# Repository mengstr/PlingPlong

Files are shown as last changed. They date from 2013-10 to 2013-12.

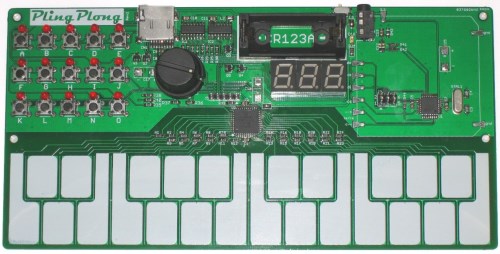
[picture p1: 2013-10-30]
Doc/PCB-r1-small.jpg

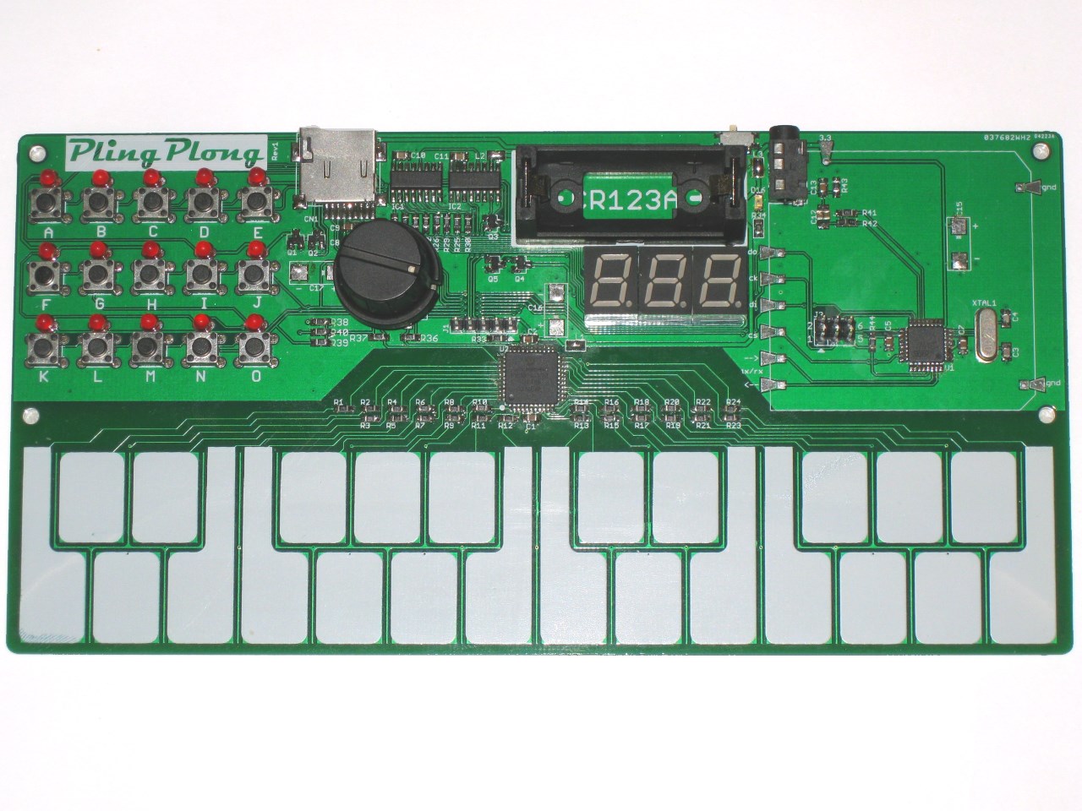
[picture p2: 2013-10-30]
Doc/PCB-r1.jpg

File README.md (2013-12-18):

## PingPlong

This is a small (10x20cm 4x8") portable battery-operated synth with a two octave touch keyboard and four voice polyphonic digital sound. A video of the board in action is available at http://youtu.be/FlVGMttL9SU

Photo of the soldered board

Two microcontrollers are used on the board - a Microchip PIC18F44K22 for the user interface and a Atmel ATMEGA328 for the sound generation.

The PIC18 is using the internal CMTU module for capacitively sensing the 24 touch keys. It is also in charge of scanning the 15 tactile buttons, refreshing the 15 status LEDs and the 7-segment displays, and polling the Rotary Encoder.

Whenever a padis touched or the rotary encoder is turned a standard Note On/Off or Control Change MIDI message is sent to the ATMEGA328 for playing.

Currently the MEGA328 is running a straight copy of the [Midi Vampire-I](http://wiki.openmusiclabs.com/wiki/MidiVamp1) firmware. The MEGA328 is also connected to a SD-card connector for future use - I want to do firmware updates via the SD card.

The sound-generating part is contained in a 5x5cm "selfcontained" area to the right on the pcb having pads and via holes for power, midi and SD-card signals. This makes it easy to replace just the synth with something else than the MidiVamp. Just design a new 5x5 cm pcb and solder it to the pads on the main board and it's done.



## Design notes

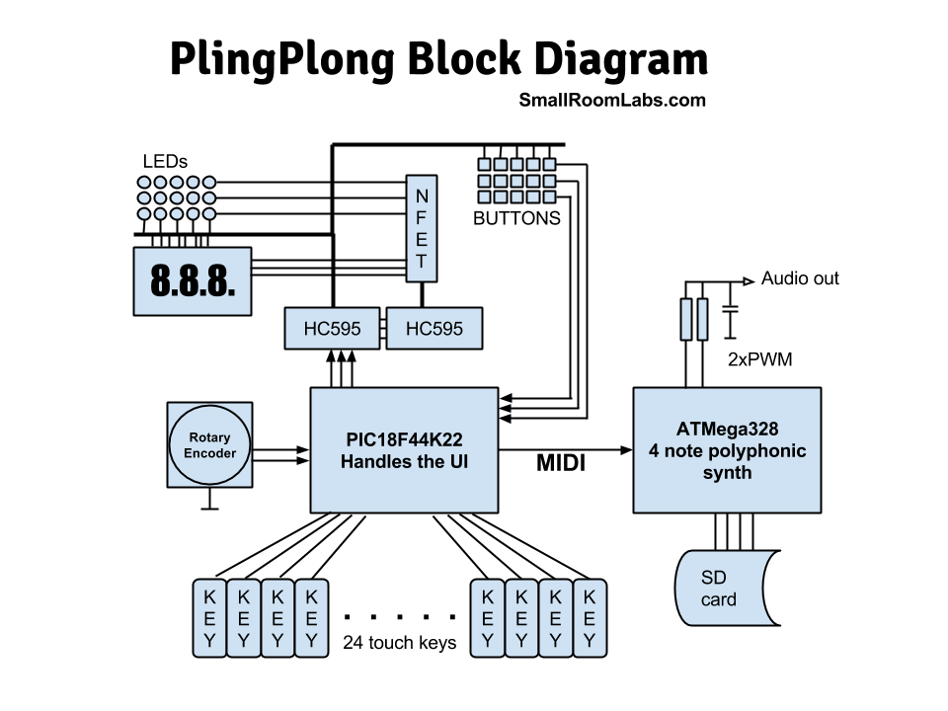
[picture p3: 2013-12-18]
Doc/PlingPlong Block diagram.png

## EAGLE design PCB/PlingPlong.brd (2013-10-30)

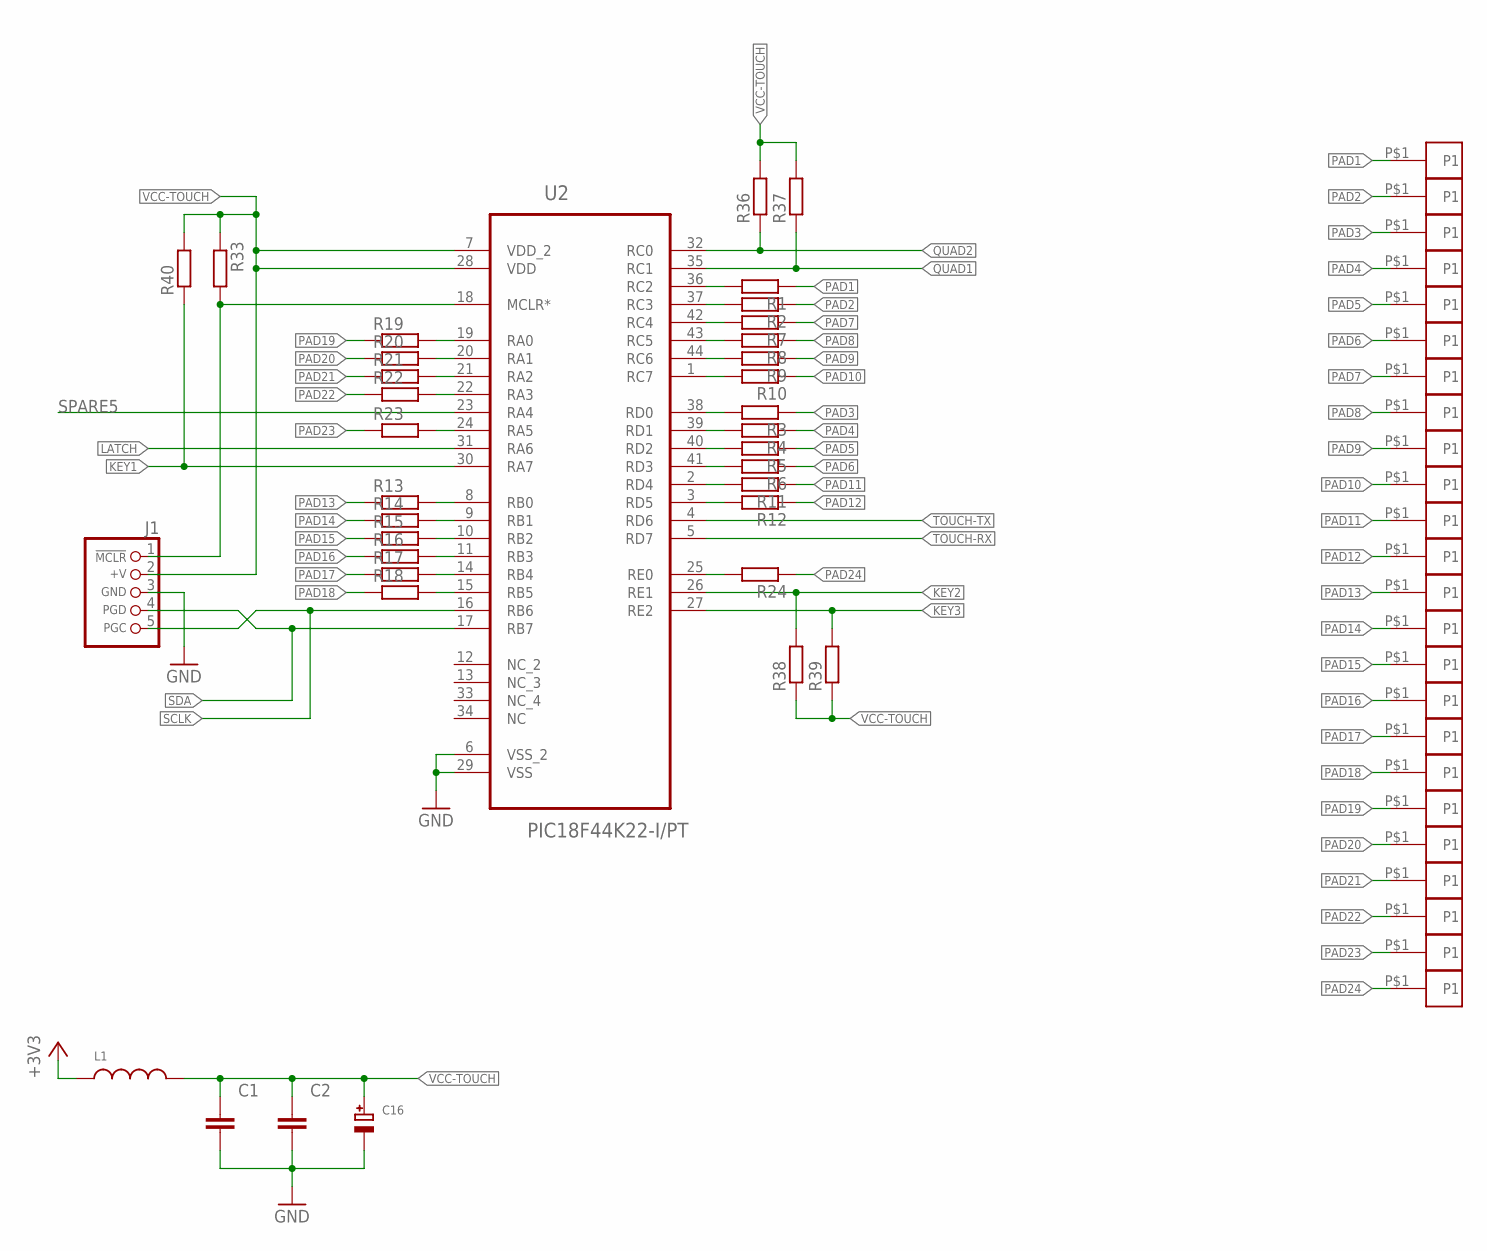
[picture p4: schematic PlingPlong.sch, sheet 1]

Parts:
C1, C2: CAPACITOR_NPOL-0805; C805
C16: CAP_TANTALUMD/7343_WAVE; EIA7343-31/D-W
J1: CON_HEADER_PRG_PIC_ICSPB; HEADER_PRG_1X05_ICSP_B
L1: INDUCTOR0805; 0805
P1, P2, P3, P4, P5, P6, P7, P8, P9, P10, P11, P12, P13, P14, P15, P16, P17, P18, P19, P20, P21, P22, P23, P24: PAD-NOSTOP; PAD1X1NOSTOP
R1, R2, R3, R4, R5, R6, R7, R8, R9, R10, R11, R12, R13, R14, R15, R16, R17, R18, R19, R20, R21, R22, R23, R24, R33, R36, R37, R38, R39, R40: R-EU_R0805W; R0805W
U2: PIC18F44K22-I/PT; QFP80P1200X1200X120-44N

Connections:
+3V3: L1.1; also elsewhere on the board
GND: C1.2, C2.2, C16.-, J1.3 (GND), U2.6 (VSS_2), U2.29 (VSS); also elsewhere on the board
KEY1: R40.1, U2.30 (RA7); also elsewhere on the board
KEY2: R38.2, U2.26 (RE1); also elsewhere on the board
KEY3: R39.2, U2.27 (RE2); also elsewhere on the board
LATCH: U2.31 (RA6); also elsewhere on the board
unnamed: R13.2, U2.8 (RB0)
unnamed: R14.2, U2.9 (RB1)
unnamed: R15.2, U2.10 (RB2)
unnamed: R16.2, U2.11 (RB3)
unnamed: R17.2, U2.14 (RB4)
unnamed: R18.2, U2.15 (RB5)
unnamed: R23.2, U2.24 (RA5)
unnamed: R19.2, U2.19 (RA0)
unnamed: R20.2, U2.20 (RA1)
unnamed: R21.2, U2.21 (RA2)
unnamed: R22.2, U2.22 (RA3)
unnamed: R1.2, U2.36 (RC2)
unnamed: R2.2, U2.37 (RC3)
unnamed: R7.2, U2.42 (RC4)
unnamed: R8.2, U2.43 (RC5)
unnamed: R9.2, U2.44 (RC6)
unnamed: R10.2, U2.1 (RC7)
unnamed: R24.2, U2.25 (RE0)
unnamed: J1.1 (/MCLR), R33.2, U2.18 (MCLR*)
unnamed: R12.2, U2.3 (RD5)
unnamed: R11.2, U2.2 (RD4)
unnamed: R6.2, U2.41 (RD3)
unnamed: R5.2, U2.40 (RD2)
unnamed: R4.2, U2.39 (RD1)
unnamed: R3.2, U2.38 (RD0)
PAD1: P1.P$1, R1.1
PAD2: P2.P$1, R2.1
PAD3: P3.P$1, R3.1
PAD4: P4.P$1, R4.1
PAD5: P5.P$1, R5.1
PAD6: P6.P$1, R6.1
PAD7: P7.P$1, R7.1
PAD8: P8.P$1, R8.1
PAD9: P9.P$1, R9.1
PAD10: P10.P$1, R10.1
PAD11: P11.P$1, R11.1
PAD12: P12.P$1, R12.1
PAD13: P13.P$1, R13.1
PAD14: P14.P$1, R14.1
PAD15: P15.P$1, R15.1
PAD16: P16.P$1, R16.1
PAD17: P17.P$1, R17.1
PAD18: P18.P$1, R18.1
PAD19: P19.P$1, R19.1
PAD20: P20.P$1, R20.1
PAD21: P21.P$1, R21.1
PAD22: P22.P$1, R22.1
PAD23: P23.P$1, R23.1
PAD24: P24.P$1, R24.1
QUAD1: R37.1, U2.35 (RC1); also elsewhere on the board
QUAD2: R36.1, U2.32 (RC0); also elsewhere on the board
SCLK: J1.5 (PGC), U2.16 (RB6); also elsewhere on the board
SDA: J1.4 (PGD), U2.17 (RB7); also elsewhere on the board
SPARE5: U2.23 (RA4)
TOUCH-RX: U2.5 (RD7); also elsewhere on the board
TOUCH-TX: U2.4 (RD6); also elsewhere on the board
VCC-TOUCH: C1.1, C2.1, C16.+, J1.2 (+V), L1.2, R33.1, R36.2, R37.2, R38.1, R39.1, R40.2, U2.7 (VDD_2), U2.28 (VDD)

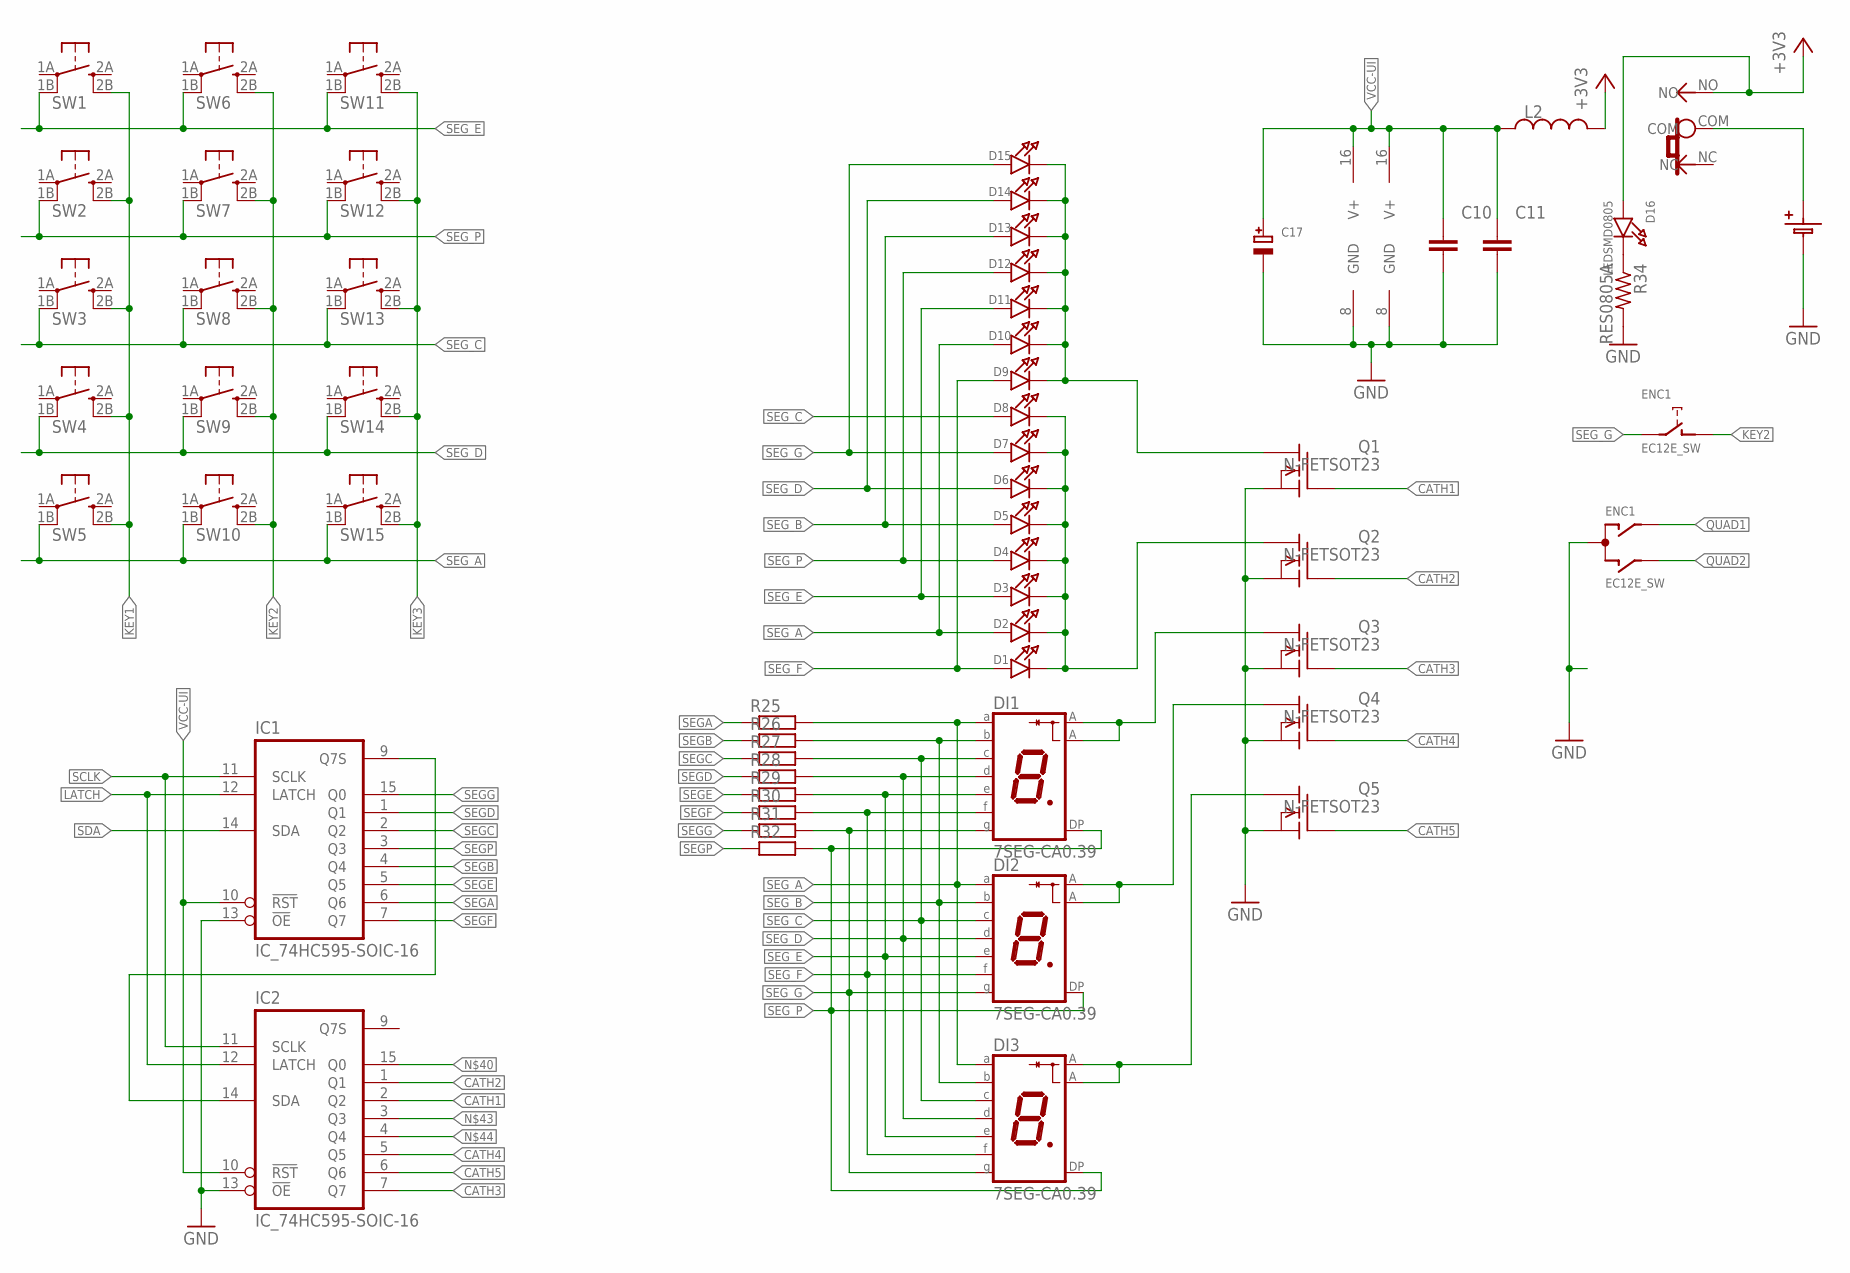
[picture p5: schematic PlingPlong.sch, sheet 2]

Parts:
BA1: BATTERY1-123PIN; BATTERY-CR123A-PINS
C10, C11: CAPACITOR_NPOL-0805; C805
C17: CAP_TANTALUMD/7343_WAVE; EIA7343-31/D-W
D1, D2, D3, D4, D5, D6, D7, D8, D9, D10, D11, D12, D13, D14, D15: LED3MM
D16: LEDSMD0805; CHIPLED_0805
DI1, DI2, DI3: 7SEG-CA0.39; LG3911
ENC1: EC12E_SW; ALPS_EC12E_SW
IC1, IC2: IC_74HC595-SOIC-16; SOIC-16
L2: INDUCTOR0805; 0805
Q1, Q2, Q3, Q4, Q5: N-FETSOT23; SOT23
R25, R26, R27, R28, R29, R30, R31, R32: R-EU_R0805W; R0805W
R34: RES0805A; R0805A
SW1, SW2, SW3, SW4, SW5, SW6, SW7, SW8, SW9, SW10, SW11, SW12, SW13, SW14, SW15: TACTILETACT-6X6-PTH; TACTILE-PTH
SW16: SLIDESWITCH-PCM12; PCM12

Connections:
+3V3: D16.A, L2.2, SW16.NO; also elsewhere on the board
CATH1: IC2.2 (Q2), Q1.1 (G)
CATH2: IC2.1 (Q1), Q2.1 (G)
CATH3: IC2.7 (Q7), Q3.1 (G)
CATH4: IC2.5 (Q5), Q4.1 (G)
CATH5: IC2.6 (Q6), Q5.1 (G)
CATH_1: D9.C, D10.C, D11.C, D12.C, D13.C, D14.C, D15.C, Q1.3 (D)
CATH_2: D1.C, D2.C, D3.C, D4.C, D5.C, D6.C, D7.C, D8.C, Q2.3 (D)
CATH_3: DI1.P$3 (A), DI1.P$8 (A), Q3.3 (D)
CATH_4: DI2.P$3 (A), DI2.P$8 (A), Q4.3 (D)
CATH_5: DI3.P$3 (A), DI3.P$8 (A), Q5.3 (D)
GND: BA1.NEG, C10.2, C11.2, C17.-, ENC1.C, IC1.8 (GND), IC1.13 (!OE), IC2.8 (GND), IC2.13 (!OE), Q1.2 (S), Q2.2 (S), Q3.2 (S), Q4.2 (S), Q5.2 (S), R34.2; also elsewhere on the board
KEY1: SW1.2B, SW2.2B, SW3.2B, SW4.2B, SW5.2B; also elsewhere on the board
KEY2: ENC1.D (1), SW6.2B, SW7.2B, SW8.2B, SW9.2B, SW10.2B; also elsewhere on the board
KEY3: SW11.2B, SW12.2B, SW13.2B, SW14.2B, SW15.2B; also elsewhere on the board
LATCH: IC1.12 (LATCH), IC2.12 (LATCH); also elsewhere on the board
unnamed: IC1.9 (Q7S), IC2.14 (SDA)
unnamed: BA1.POS (POS1), SW16.COM
unnamed: D16.C, R34.1
QUAD1: ENC1.A; also elsewhere on the board
QUAD2: ENC1.B; also elsewhere on the board
SCLK: IC1.11 (SCLK), IC2.11 (SCLK); also elsewhere on the board
SDA: IC1.14 (SDA); also elsewhere on the board
SEGA: IC1.6 (Q6), R25.1
SEGB: IC1.4 (Q4), R26.1
SEGC: IC1.2 (Q2), R27.1
SEGD: IC1.1 (Q1), R28.1
SEGE: IC1.5 (Q5), R29.1
SEGF: IC1.7 (Q7), R30.1
SEGG: IC1.15 (Q0), R31.1
SEGP: IC1.3 (Q3), R32.1
SEG_A: D2.A, D10.A, DI1.P$10 (A), DI2.P$10 (A), DI3.P$10 (A), R25.2, SW5.1B, SW10.1B, SW15.1B
SEG_B: D5.A, D13.A, DI1.P$9 (B), DI2.P$9 (B), DI3.P$9 (B), R26.2
SEG_C: D8.A, DI1.P$7 (C), DI2.P$7 (C), DI3.P$7 (C), R27.2, SW3.1B, SW8.1B, SW13.1B
SEG_D: D6.A, D14.A, DI1.P$5 (D), DI2.P$5 (D), DI3.P$5 (D), R28.2, SW4.1B, SW9.1B, SW14.1B
SEG_E: D3.A, D11.A, DI1.P$2 (E), DI2.P$2 (E), DI3.P$2 (E), R29.2, SW1.1B, SW6.1B, SW11.1B
SEG_F: D1.A, D9.A, DI1.P$1 (F), DI2.P$1 (F), DI3.P$1 (F), R30.2
SEG_G: D7.A, D15.A, DI1.P$6 (G), DI2.P$6 (G), DI3.P$6 (G), ENC1.E (2), R31.2
SEG_P: D4.A, D12.A, DI1.P$4 (DP), DI2.P$4 (DP), DI3.P$4 (DP), R32.2, SW2.1B, SW7.1B, SW12.1B
VCC-UI: C10.1, C11.1, C17.+, IC1.10 (!RST), IC1.16 (V+), IC2.10 (!RST), IC2.16 (V+), L2.1

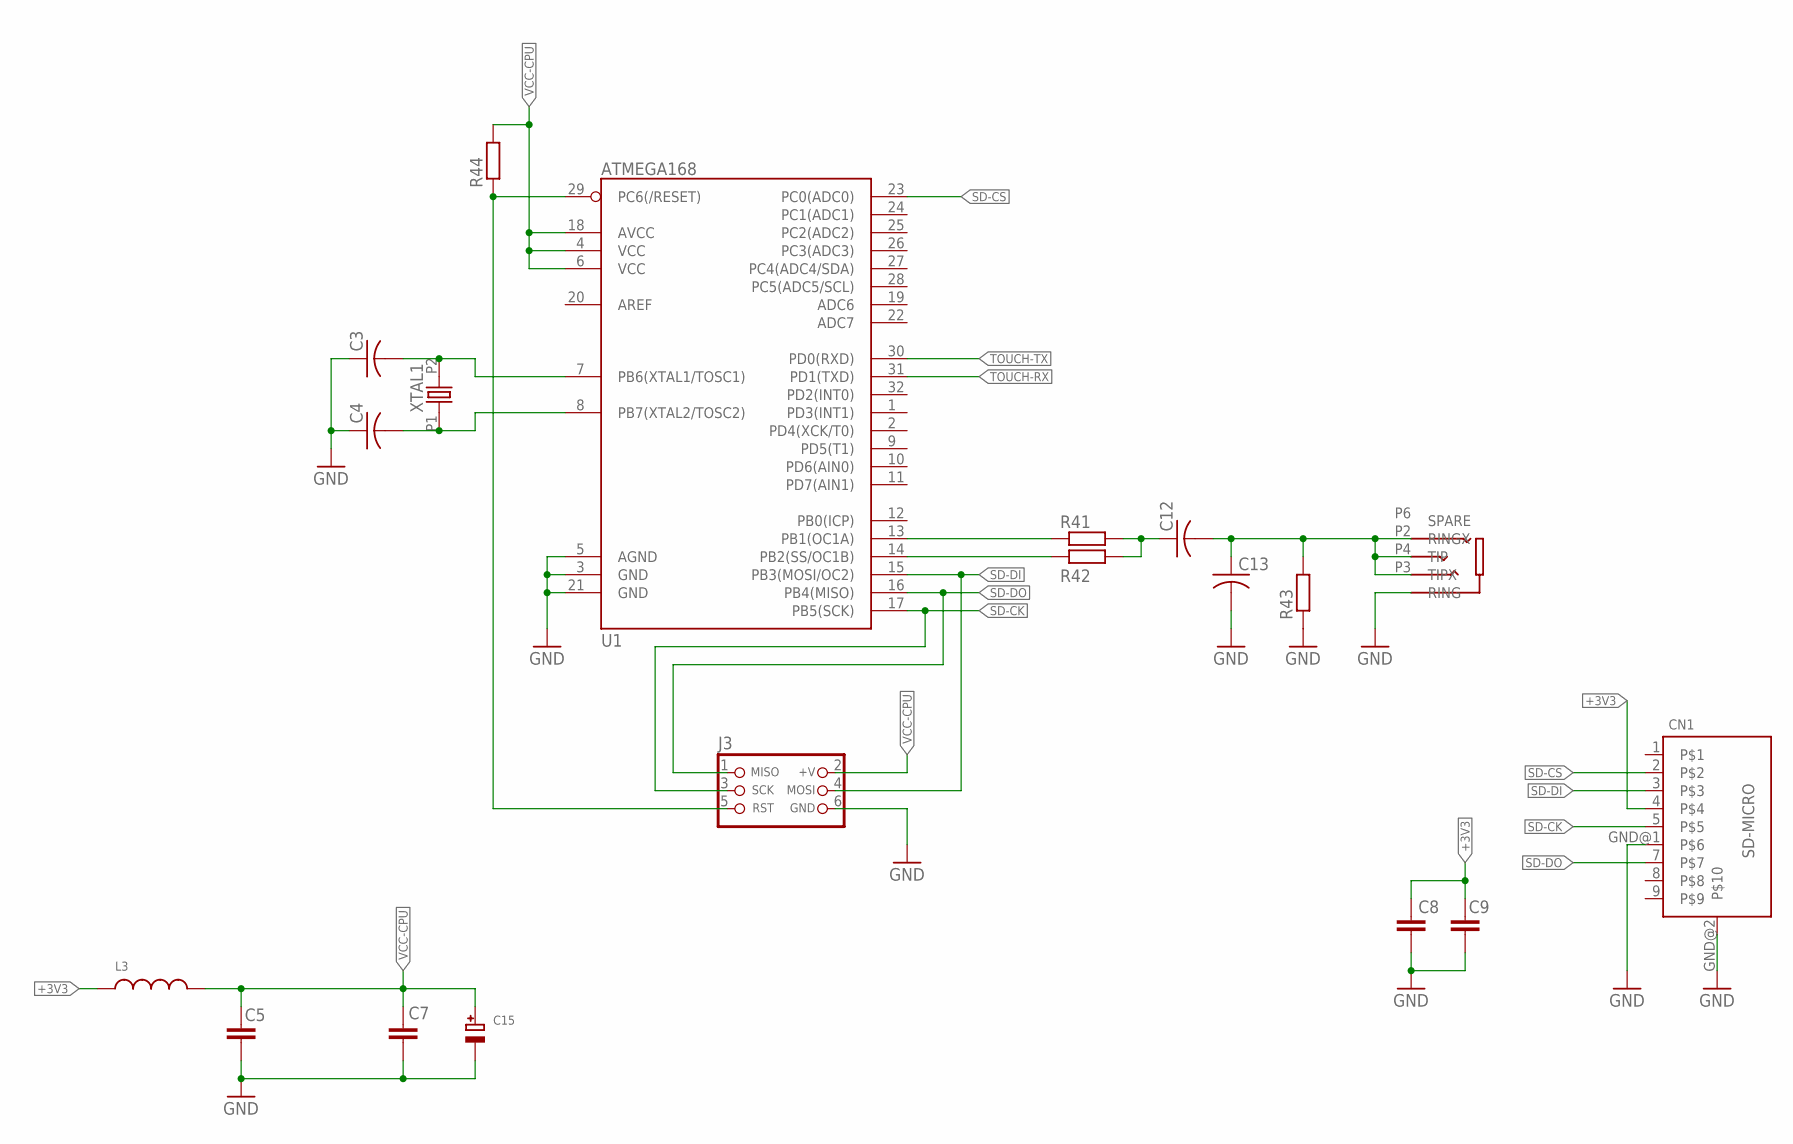
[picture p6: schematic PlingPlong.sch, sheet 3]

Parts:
C3, C4, C13: C-USC0805; C0805
C5, C7, C8, C9: CAPACITOR_NPOL-0805; C805
C12: C-USC1206; C1206
C15: CAP_TANTALUMD/7343_WAVE; EIA7343-31/D-W
CN1: SD-MICRO; MICROSD-TFP09
J3: CON_HEADER_PRG_AVR_ICSP; HEADER_PRG_2X03
L3: INDUCTOR0805; 0805
R41, R42, R43, R44: R-EU_R0805W; R0805W
U1: ATMEGA168; TQFP32-08
U$2: JACK4-PJ320; PJ-320E
XTAL1: OSC-XTAL-HC-49U-PTH; HC-49U-PTH

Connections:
+3V3: C8.1, C9.1, CN1.4, L3.1; also elsewhere on the board
CPU-RESET: J3.5 (RST), R44.1, U1.29 (PC6(/RESET))
GND: C3.1, C4.1, C5.2, C7.2, C8.2, C9.2, C13.2, C15.-, CN1.GND@1, CN1.GND@2, J3.6 (GND), R43.1, U1.3 (GND), U1.5 (AGND), U1.21 (GND), U$2.P5 (RING); also elsewhere on the board
unnamed: R41.1, U1.13 (PB1(OC1A))
unnamed: R42.1, U1.14 (PB2(SS/OC1B))
unnamed: C12.1, R41.2, R42.2
unnamed: C12.2, C13.1, R43.2, U$2.P2 (RINGX), U$2.P3 (TIPX), U$2.P4 (TIP)
unnamed: C3.2, U1.7 (PB6(XTAL1/TOSC1)), XTAL1.P2 (2)
unnamed: C4.2, U1.8 (PB7(XTAL2/TOSC2)), XTAL1.P1 (1)
SD-CK: CN1.5, J3.3 (SCK), U1.17 (PB5(SCK))
SD-CS: CN1.2, U1.23 (PC0(ADC0))
SD-DI: CN1.3, J3.4 (MOSI), U1.15 (PB3(MOSI/OC2))
SD-DO: CN1.7, J3.1 (MISO), U1.16 (PB4(MISO))
TOUCH-RX: U1.31 (PD1(TXD)); also elsewhere on the board
TOUCH-TX: U1.30 (PD0(RXD)); also elsewhere on the board
VCC-CPU: C5.1, C7.1, C15.+, J3.2 (+V), L3.2, R44.2, U1.4 (VCC), U1.6 (VCC), U1.18 (AVCC)

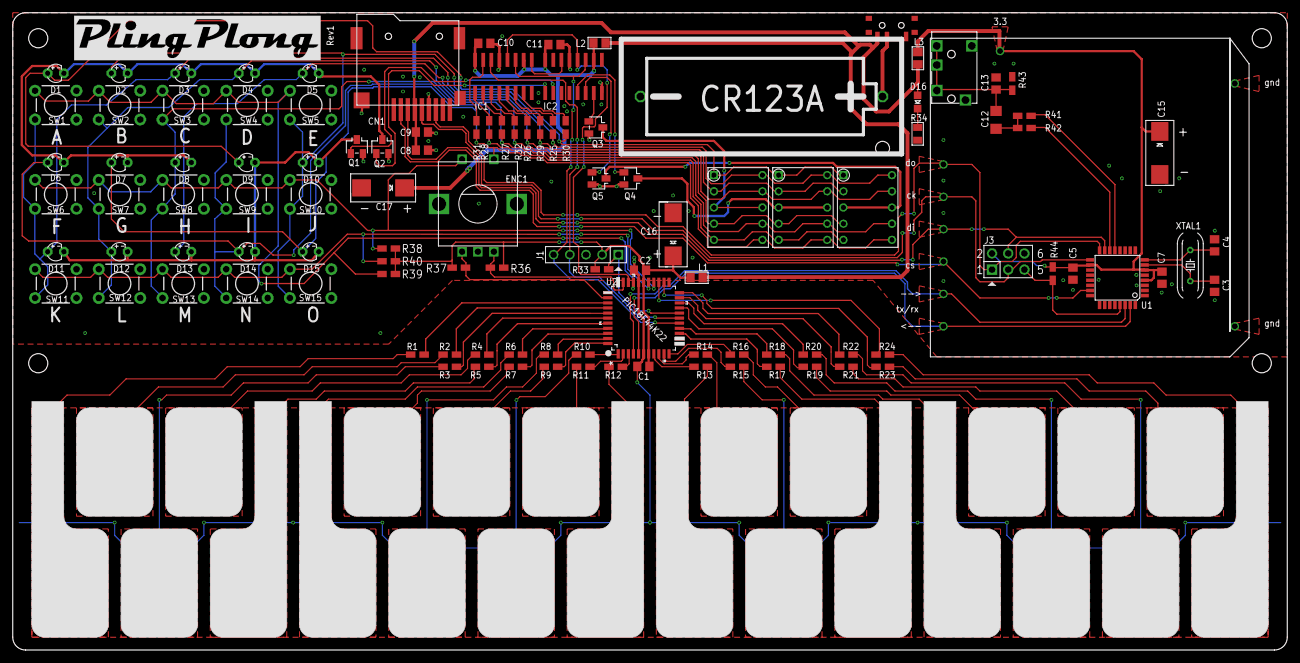
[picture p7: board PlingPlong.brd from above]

Board: 2 copper layers, 200.0 x 100.0 mm, 136 parts (0 on the bottom side), 104 nets.

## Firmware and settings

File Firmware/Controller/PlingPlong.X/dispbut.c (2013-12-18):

#include <stdint.h>         /* For uint8_t definition */
#include <stdbool.h>        /* For true/false definition */
#include <xc.h>
#include "dispbut.h"

#define KEY1            PORTAbits.RA7
#define KEY2            PORTEbits.RE1
#define KEY3            PORTEbits.RE2

#define LATCH595        LATAbits.LA6
#define CLK595          LATBbits.LB6
#define DATA595         LATBbits.LB7


volatile uint8_t    disp[3];
volatile uint16_t   leds;
volatile uint16_t   keys;
volatile uint8_t    butt;

const uint8_t charmap[]={
    0x00,0x82,0x21,0x00,0x00,0x00,0x00,0x02,0x39,0x0f,0x00,0x00,0x00,0x40,0x80,0x52,	//  !"#$%&'()*+,-./
    0x3f,0x06,0x5b,0x4f,0x66,0x6d,0x7d,0x07,0x7f,0x6f,0x09,0x00,0x00,0x48,0x00,0x53,	// 0123456789:;<=>?
    0x00,0x77,0x7c,0x39,0x5e,0x79,0x71,0x6f,0x76,0x06,0x1e,0x70,0x38,0x37,0x54,0x3f,	// @ABCDEFGHIJKLMNO
    0x73,0x67,0x50,0x6d,0x78,0x3e,0x00,0x00,0x00,0x6e,0x00,0x39,0x00,0x0f,0x00,0x08,	// PQRSTUVWXYZ[\]^
    0x63,0x5f,0x7c,0x58,0x5e,0x7b,0x71,0x6f,0x74,0x02,0x1e,0x00,0x06,0x00,0x54,0x5c,	// `abcdefghijklmno
    0x73,0x67,0x50,0x6d,0x78,0x1c,0x00,0x00,0x00,0x6e,0x00,0x39,0x30,0x0f,0x00,0x00, 	// pqrstuvwxyz{|}~
    };



void ShiftBit(bool v) {
    if (v) DATA595=1; else DATA595=0;
    NOP();
    CLK595=1;
    NOP();
    CLK595=0;
}

void ShiftByte(uint8_t v) {
    ShiftBit(v&0x80);
    ShiftBit(v&0x40);
    ShiftBit(v&0x20);
    ShiftBit(v&0x10);
    ShiftBit(v&0x08);
    ShiftBit(v&0x04);
    ShiftBit(v&0x02);
    ShiftBit(v&0x01);
}



void RefreshDisp(void) {
    static uint8_t cath=0;
    uint8_t v;
    uint8_t no;

    cath++;
    if (cath==6) {
        cath=0;
    }

    if (cath==0) {
        keys=0;
        butt=0;

        LATCH595=0;
        ShiftByte(0x00);
        ShiftByte(~0x20);
        LATCH595=1;
        NOP();
        NOP();
        NOP();
        NOP();
        NOP();
        if (KEY1==0) keys|=0x0001;
        if (KEY2==0) keys|=0x0020;
        if (KEY3==0) keys|=0x0400;

        LATCH595=0;
        ShiftByte(0x00);
        ShiftByte(~0x08);
        LATCH595=1;
        NOP();
        NOP();
        NOP();
        NOP();
        NOP();
        if (KEY1==0) keys|=0x0002;
        if (KEY2==0) keys|=0x0040;
        if (KEY3==0) keys|=0x0800;

        LATCH595=0;
        ShiftByte(0x00);
        ShiftByte(~0x04);
        LATCH595=1;
        NOP();
        NOP();
        NOP();
        NOP();
        NOP();
        if (KEY1==0) keys|=0x0004;
        if (KEY2==0) keys|=0x0080;
        if (KEY3==0) keys|=0x1000;

        LATCH595=0;
        ShiftByte(0x00);
        ShiftByte(~0x02);
        LATCH595=1;
        NOP();
        NOP();
        NOP();
        NOP();
        NOP();
        if (KEY1==0) keys|=0x0008;
        if (KEY2==0) keys|=0x0100;
        if (KEY3==0) keys|=0x2000;

        LATCH595=0;
        ShiftByte(0x00);
        ShiftByte(~0x40);
        LATCH595=1;
        NOP();
        NOP();
        NOP();
        NOP();
        NOP();
        if (KEY1==0) keys|=0x0010;
        if (KEY2==0) keys|=0x0200;
        if (KEY3==0) keys|=0x4000;

        LATCH595=0;
        ShiftByte(0x00);
        ShiftByte(~0x01);
        LATCH595=1;
        NOP();
        NOP();
        NOP();
        NOP();
        NOP();
        if (KEY2==0) butt=1;

        return;
    }

    v=0;
    if (cath==1) {
        if (leds&0x0100) v|=0x80;
        if (leds&0x0200) v|=0x40;
        if (leds&0x0400) v|=0x20;
        if (leds&0x0800) v|=0x08;
        if (leds&0x1000) v|=0x10;
        if (leds&0x2000) v|=0x02;
        if (leds&0x4000) v|=0x01;
    }
    if (cath==2) {
        if (leds&0x0001) v|=0x80;
        if (leds&0x0002) v|=0x40;
        if (leds&0x0004) v|=0x20;
        if (leds&0x0008) v|=0x08;
        if (leds&0x0010) v|=0x10;
        if (leds&0x0020) v|=0x02;
        if (leds&0x0040) v|=0x01;
        if (leds&0x0080) v|=0x04;
    }
    if (cath==3 || cath==4 || cath==5) {
        no=cath-3;
        if (disp[no]&0x01) v|=0x40;     // SEG_A ~
        if (disp[no]&0x02) v|=0x10;     // SEG_B ~
        if (disp[no]&0x04) v|=0x04;     // SEG_C ~
        if (disp[no]&0x08) v|=0x02;     // SEG_D ~
        if (disp[no]&0x10) v|=0x08;     // SEG_E
        if (disp[no]&0x20) v|=0x20;     // SEG_F
        if (disp[no]&0x40) v|=0x80;     // SEG_G
        if (disp[no]&0x80) v|=0x01;     // SEG_H
    }

    LATCH595=0;
    ShiftBit(cath==3);
    ShiftBit(cath==5);
    ShiftBit(cath==4);
    ShiftBit(false);
    ShiftBit(false);
    ShiftBit(cath==1);
    ShiftBit(cath==2);
    ShiftBit(false);
    ShiftByte(v);
    LATCH595=1;
}


void DispValue(uint16_t value) {
    uint16_t t;
    uint8_t dp0,dp1,dp2;
    t=value;

    dp0=0;
    dp1=0;
    dp2=0;
    if (t>3999) {
        t=0;
        dp0=0x80;
        dp1=0x80;
        dp2=0x80;
    } else if (t>2999) {
        dp0=0x80;
        t=t-3000;
    } else if (t>1999) {
        dp1=0x80;
        t=t-2000;
    } else if (t>999) {
        dp2=0x80;
        t=t-1000;
    }
    disp[2]=charmap[16+(t%10)] | dp2;
    t=t/10;
    disp[1]=charmap[16+(t%10)] | dp1;
    t=t/10;
    disp[0]=charmap[16+(t%10)] | dp0;
}

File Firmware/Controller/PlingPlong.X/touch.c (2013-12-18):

#include <stdint.h>         // uint8_t definitions
#include <xc.h>
#include "config.h"
#include "touch.h"

const uint8_t PADMAP[PADS]={14,15,20,21,22,23,16,17,18,19,24,25,12,10,8,9,11,13,0,1,2,3,4,5};
volatile int16_t padBase[PADS];



int16_t GetPadBaseValue(uint8_t no) {
    return padBase[no];
}


/**************************************************************************/
/*Set up CTMU *****************************************************************/
/**************************************************************************/
void SetupCTMU(void) {
    //CTMUCONH/1 - CTMU Control registers
    CTMUCONH = 0x00; //make sure CTMU is disabled
    CTMUCONL = 0x90;
    //CTMU continues to run when emulator is stopped,CTMU continues
    //to run in idle mode,Time Generation mode disabled, Edges are blocked
    //No edge sequence order, Analog current source not grounded, trigger
    //output disabled, Edge2 polarity = positive level, Edge2 source =
    //source 0, Edge1 polarity = positive level, Edge1 source = source 0,
    //CTMUICON - CTMU Current Control Register
    CTMUICON = 0x03; //0.55uA*100=55uA, Nominal - No Adjustment
    /**************************************************************************/
    //Set up AD converter;
    /**************************************************************************/
    // ADCON2
    ADCON2bits.ADFM=1; // Results format 1= Right justified
    ADCON2bits.ACQT=1; // Acquition time 7 = 20TAD 2 = 4TAD 1=2TAD
    ADCON2bits.ADCS=2; // Clock conversion bits 6= FOSC/64 2=FOSC/32
    // ADCON1
    ADCON1bits.PVCFG0 =0; // Vref+ = AVdd
    ADCON1bits.NVCFG1 =0; // Vref- = AVss
    // ADCON0
    ADCON0bits.ADON=1; // Turn on ADC
}





uint16_t ReadPad(uint8_t no) {
    uint32_t v;
    uint8_t i;

    v=0;
    for (i=0; i<TOUCHOVERSAMPLE; i++) {
        ADCON0bits.CHS=PADMAP[no];      // Select ADC channel
        CTMUCONHbits.CTMUEN = 1;        // Enable the CTMU
        CTMUCONLbits.EDG1STAT = 0;      // Set Edge status bits to zero
        CTMUCONLbits.EDG2STAT = 0;
        CTMUCONHbits.IDISSEN = 1;       //drain charge on the circuit
        __delay_us(DISCHARGETIME);
        CTMUCONHbits.IDISSEN = 0;       //end drain of circuit
        di();
        CTMUCONLbits.EDG1STAT = 1;      //Begin charging the circuit using CTMU current source
        __delay_us(CHARGETIME);
        CTMUCONLbits.EDG1STAT = 0;      //Stop charging circuit
        PIR1bits.ADIF = 0;              //make sure A/D Int not set
        ADCON0bits.GO=1;                //and begin A/D conv.
        while(!PIR1bits.ADIF);          //Wait for A/D convert complete
        ei();
        v+=ADRES;                        //Get the value from the A/D
    }
    return v/TOUCHOVERSAMPLE;
}



void CalibratePads(void) {
    uint8_t i,j;
    uint16_t avg;

    for (i=0; i<PADS; i++) {
        avg=0;
        for (j=0; j<CALIBRATEOVERSAMPLE; j++) {
            __delay_ms(1);
            avg+=ReadPad(i);
        }
        avg=avg/CALIBRATEOVERSAMPLE;
        padBase[i]=avg;
    }
}

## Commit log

2013-10-30 Rev 1
    [PlingPlong.GBL, PlingPlong.GBO, PlingPlong.GBP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]
2013-10-30 Photo of soldered pcb
2013-10-30 Small photo of soldered pcb

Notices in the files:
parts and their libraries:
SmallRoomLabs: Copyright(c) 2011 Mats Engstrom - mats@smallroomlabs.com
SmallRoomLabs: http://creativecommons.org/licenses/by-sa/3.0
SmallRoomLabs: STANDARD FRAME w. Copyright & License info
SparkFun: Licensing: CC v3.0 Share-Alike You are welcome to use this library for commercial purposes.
